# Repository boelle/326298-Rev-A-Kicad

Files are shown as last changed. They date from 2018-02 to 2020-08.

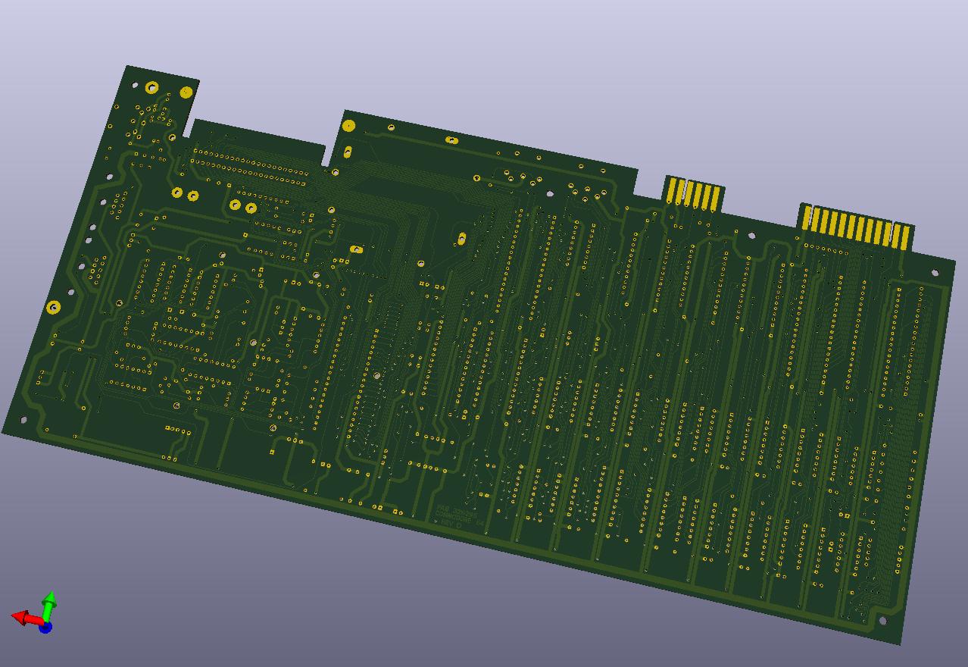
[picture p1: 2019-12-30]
GERBERS/back_3d.jpg

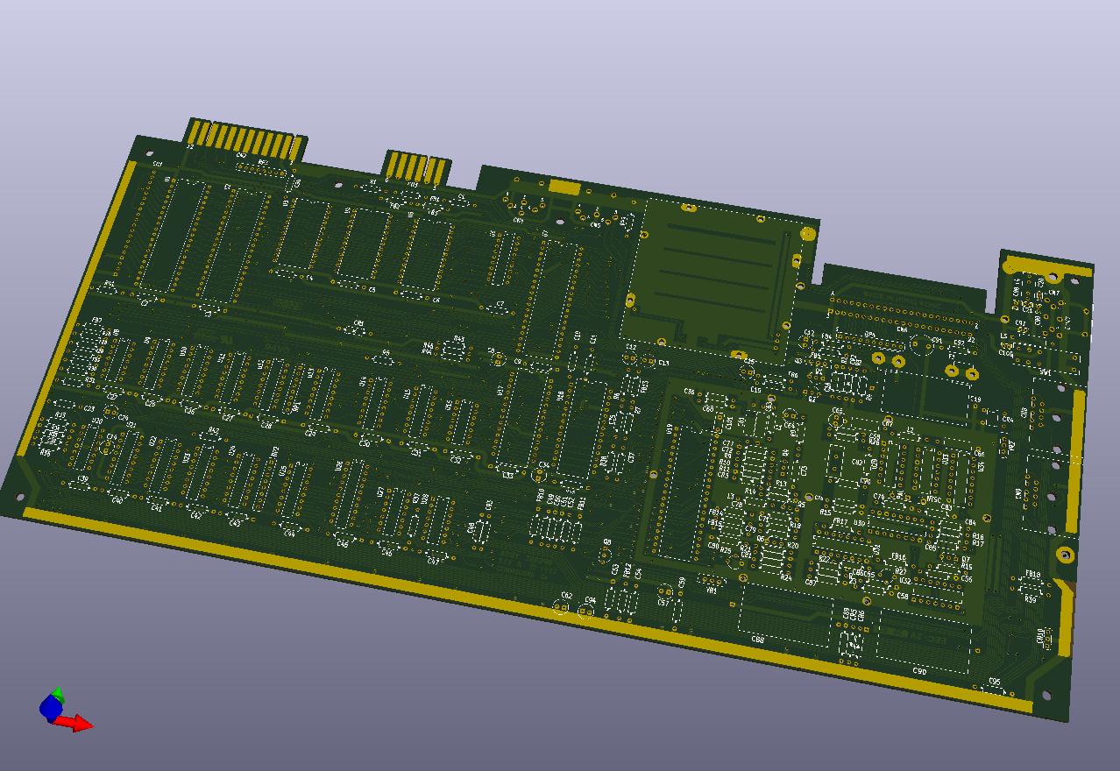
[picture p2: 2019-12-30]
GERBERS/front_3d.jpg

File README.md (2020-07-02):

Shield: [][cc-by-nc-nd]

This work is licensed under a [Attribution-NonCommercial-NoDerivatives 4.0 International License][cc-by-nc-nd].

[][cc-by-nc-nd]

[cc-by-nc-nd]: http://creativecommons.org/licenses/by-nc-nd/4.0/
[cc-by-nc-nd-image]: https://licensebuttons.net/l/by-nc-nd/4.0/88x31.png
[cc-by-nc-nd-shield]: https://img.shields.io/badge/License-CC%20BY--NC--ND%204.0-lightgrey.svg

# What is this?

It's my project/attempt at recreating the first board used in C64 production.
It's based on a schematic by Ruud Baltissen.

# How?
I got one of these boards without much components, all chips where gone (almost).
I then removed the rest and cleaned out all holes and got it scanned at a local copy shop.
Initial I used sprint layout which has a feature to trace on top of an image.
But I wanted a more "complete" soloution so I imported the copper layers in to kicad and 
managed to trace on top of that. 
But the schematic was not the same as the board and I got help from Fredric QJ Blåholtz
adjustning the schematic to the board, it's a bit backwards but I trust the board more.

# Why?
I have been asked that a lot. One reason is that I have always liked the C64 and I
wanted to get more intimate with it. One thing I have truly learned is that QA and QC 
was not that much used 37 years ago, anything that worked was ok. So boards could differ 
even thou they had the same number. So I decided to just stick with making a replica of
what I had. 

The other reason is that I have a lot of time on my hands so I wanted to make
something, that at some point will come in as usefull. These boards will at some point fail.
They where not robust made 37 years ago and either a hole will break loose from the board
or a track will crack. Having a source for a new board would then come in handy. Simply
pick a PCB house that you trust and send them the gerber files. Most have a minimum order
so you will never have a problem again.

# Status?
I have verified the board by printing out the tracks on paper and used a needle to poke
through and see if things match up. It does very close but since paper under the real board
can move it will not be precise, but it's as good as I can do it.

I have also added some "eyecandy" in the form of 3d shapes of most things on the board. 
there are some things I can't find thou and my skills are not up to doing that from scratch,
but if anyone wants to chip in I need step/stp files for these parts:

# Plan?
At summer 2020 I will order 5 boards as that is the minimum from Elecrow. I will then
during fall/winter buy and add components. Since the chips are the most expensive parts,
it might be as far as early 2021 before i can power it up

# Working on right now?
Trying to locate cad/3d models in step/stp format for the missing bits

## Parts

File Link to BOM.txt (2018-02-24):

https://docs.google.com/spreadsheets/d/1Gl0Q71u6fKLPRA9HQiSG8-xY8tPweMwXuy_UGQ1Iayo/edit?usp=sharing

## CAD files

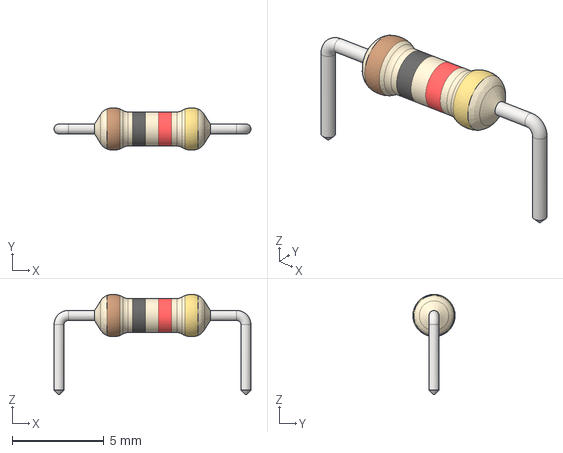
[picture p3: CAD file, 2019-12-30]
1 Kohm resistor/1,0 kOhm R Axial DIN0207 L6.3mm D2.5mm P10.16mm Horizontal.stp
10.7 x 2.30 x 5.45 mm

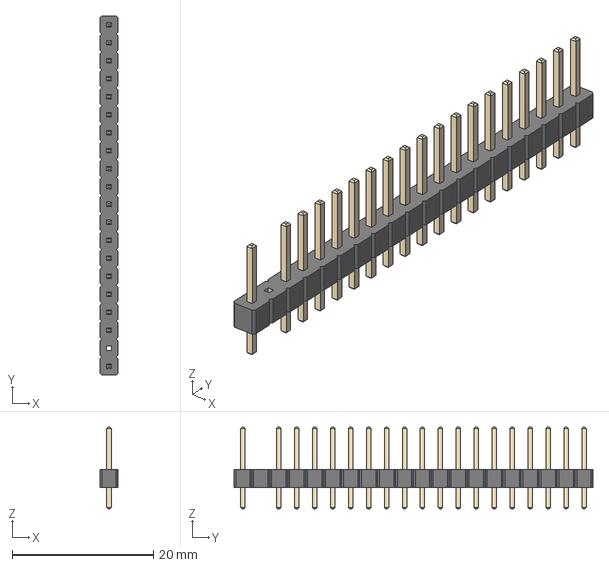
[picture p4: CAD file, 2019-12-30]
1x20 pin connector/PinHeader_1x20_P2.54mm_Vertical.step
2.54 x 50.8 x 11.5 mm

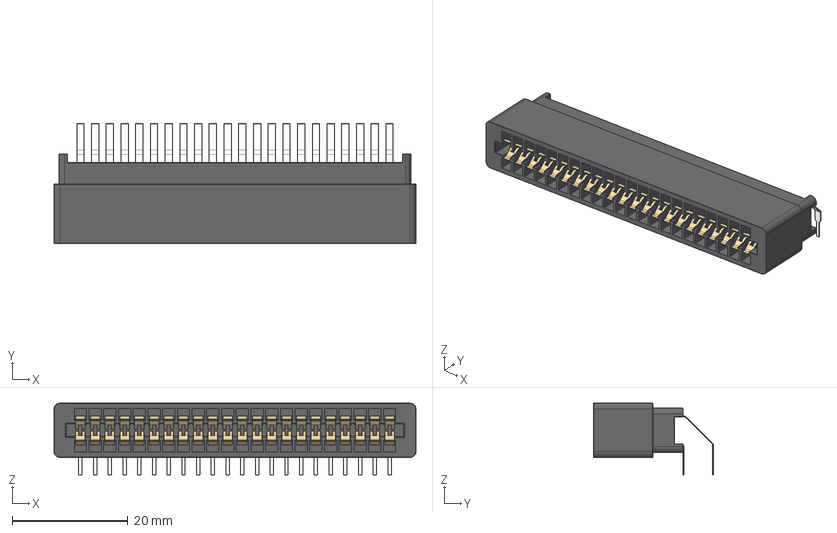
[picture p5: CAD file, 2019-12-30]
44 pin edge connector/EDGE PCB Connector P2.54mm 44pin 2 Rows Right Angle.stp
62.5 x 20.7 x 12.3 mm
EDGE Card Connector 44pos Body
EDGE Connector 2.54mm Contact Right Angle Upper x 22
EDGE Connector 2.54mm Contact Right Angle Lower x 22

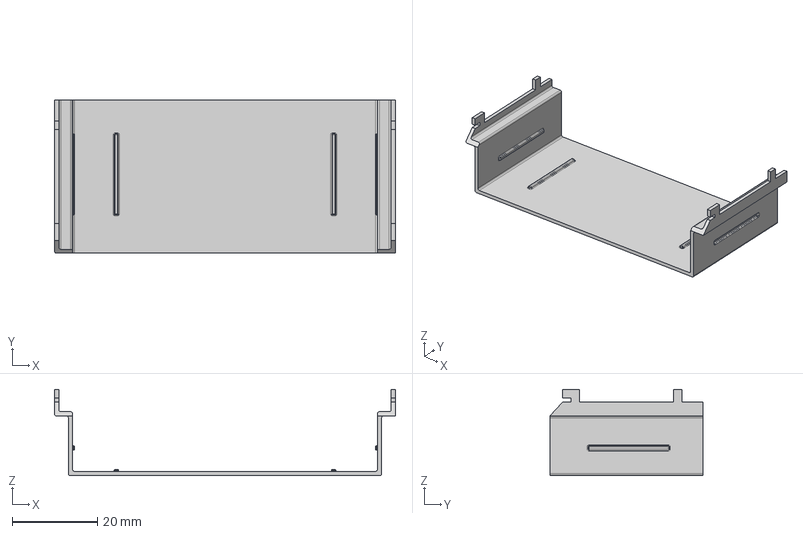
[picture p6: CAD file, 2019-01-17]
exp. port bracket/exp. port bracket.step
80.0 x 36.0 x 20.2 mm

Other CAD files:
1 Mohm resistor/1,0 MOhm R Axial DIN0207 L6.3mm D2.5mm P10.16mm Horizontal.stp
1.2 Kohm resistor/1,2 kOhm R Axial DIN0207 L6.3mm D2.5mm P10.16mm Horizontal.stp
1.5 Kohm resistor/1,5 kOhm R Axial DIN0207 L6.3mm D2.5mm P10.16mm Horizontal.stp
10 Kohm resistor/10,0 kOhm R Axial DIN0207 L6.3mm D2.5mm P10.16mm Horizontal.stp
100 Ohm resistor/100,0 Ohm R Axial DIN0207 L6.3mm D2.5mm P10.16mm Horizontal.stp
120 Ohm resistor/120,0 Ohm R Axial DIN0207 L6.3mm D2.5mm P10.16mm Horizontal.stp
3.3kohm resistor/3,3 kOhm R Axial DIN0207 L6.3mm D2.5mm P10.16mm Horizontal.stp
390 Ohm resistor/390,0 Ohm R Axial DIN0207 L6.3mm D2.5mm P10.16mm Horizontal.stp
4.7 Kohm resistor/4,7 kOhm R Axial DIN0207 L6.3mm D2.5mm P10.16mm Horizontal.stp
47 Kohm resistor/47,0 kOhm R Axial DIN0207 L6.3mm D2.5mm P10.16mm Horizontal.stp
470 Kohm resistor/470,0 kOhm R Axial DIN0207 L6.3mm D2.5mm P10.16mm Horizontal.stp
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

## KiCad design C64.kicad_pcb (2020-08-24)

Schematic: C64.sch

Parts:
C1, C2, C3, C16, C18, C22, C30, C31, C32, C35, C39, C45, C46, C47, C55, C56, C58, C68, C71, C74, C76, C77, C82, C84, C87, C89, C95, C96: 0.1 uF; 12_03_07
C4, C5, C6, C7, C9, C29, C33, C44, C51, C60, C85: 0.47 uF; 12_03_07
C8, C12, C13, C14, C15, C17, C24, C34, C57, C62, C64, C65, C94: 10 uF 25V; CAPACITOR_ELECTROLYTIC_2.5_6
C10, C11: 2200 pF Polyester; polyester12_03_07
C19: 2200 uF 16V; E37-31.5-17.5-E
C20, C21, C97, C98, C99, C100: 0.22 uF 100V; 0203
C23: 360 pF; 12_03_07
C25, C26, C27, C28, C40, C41, C42, C43, C50, C54, C59, C92: 0.22 uF; 12_03_07
C36: 20 pF 50V; 12_03_07
C37, C48, C93: 1000 pF; 12_03_07
C38, C80: 51 pF; 12_03_07
C49, C52: 470 pF 50V; 12_03_07
C53: 470 pF; 12_03_07
C61, C63, C66, C67: 0.47 uF 50V 20%; 15_4_10
C70: 10 pF 5%; 12_03_07
C72, C78: 220 pF 50V; 12_03_07
C73: 150 pF 50V; 12_03_07
C79: 510 pF; 12_03_07
C81: 20 pF; 12_03_07
C83: 33 pF; 12_03_07
C86: 39 pF 50V 5%; 12_03_07
C88, C90: 470 uF 50V; E37-31.5-17.5-E
C91: 100 uF 16V; C_E_5-9
C101: 0.1 uF; P5
CN1: KEYBOARD; 20way
CN2: USERPORT
CN3: CASSETTEPORT
CN4: DIN6
CN5: DIN5
CN6: EXPANSIONPORT
CN7: DIN7
CN8, CN9: CONTROL_PORT
CR1: 1N4371 2.7 V; D-12_3_7
CR2: 7.5 V; D-12_3_7
CR3: 1N914; D-12_3_7
CR4: BRIDGE_RECTIFIER
CR5, CR6: 1N4001; D-12_3_7
F1: 1A; SH32
FB1, FB2, FB3, FB4, FB5, FB6, FB7, FB8, FB9, FB10, FB11, FB12, FB13, FB14, FB15, FB16, FB17, FB18: FERRITE_BEAD
FRAME1: FRAME_D_L
J1, J2, J3: Conn_01x01; Socket_Strip_Straight_1x01_Pitch2.54mm
JP2E1: CN10; 3way
L1, L2: 2.2 uH; 12_03_07
L3: 3 uH; 12_03_07
L4: LINEFILTER
L5: 1.2 uH; P15
Q1: 2N4401; TO92
Q2: 2N3904; TO92
Q3: TIP29B
Q4, Q5, Q6, Q7, Q8: PN2222; TO92
R1, R24, R43, R44, R45: 3.3 K; 12_03_07
R2, R5, R15, R22: 1.5 K; 12_03_07
R3, R7: 10 K; 12_03_07
R4, R6, R13, R16, R23, R28, R29, R30, R31, R36, R38: 1 K; 12_03_07
R8, R39: 390; 12_03_07
R9, R26: 75; 12_03_07
R10, R11: 120; 12_03_07
R14: 100; 12_03_07
R17: 1.2 K; 12_03_07
R18: 230; 12_03_07
R19: 15 K; 12_03_07
R20, R37: 6.8 K; 12_03_07
R21: 4.7 K; 12_03_07
R25: 1 K Trim Pot; POT_METER
R27: 2 K Trim Pot; POT_METER
R33, R34: 47 K; 12_03_07
R35: 470 K; 12_03_07
R41: 1 M; 12_03_07
R42: 0; 12_03_07
R46: 2.1 K; 12_03_07
R49: 470; 12_03_07
RF1: RF-MODULATOR
RP1, RP2: 33; RESISTOR_PACK_4
RP3: 3.3 K; RESISTOR_PACK_4
RP4: 3.3 K; RESISTOR_PACK_9
SW1: DPDT_SWITCH
U1, U2: 6526
U3, U4: 2364
U5: 2332
U6: 2114
U7: 6510
U8: SN7406NN
U9, U10, U11, U12, U21, U22, U23, U24: 4164
U13, U25: SN74257N
U14: SN74258N
U15: SN74139N
U16, U28: 4066
U17: C64PLA
U18: 6581
U19: 6569
U20: 556DIGITAL
U26: SN74373N; 74373N
U27: SN7408N
U29: SN7474N
U30: SN74193N
U31: SN74629
U32: MC4044
U33: 74LS02; 7402
U34: 74LS175; SN74629
VR1: 7812; VR
VR2: 7805; VR
Y1: 17.73 MHz; HC49TL-H

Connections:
/+5Vc: C55.1, C56.1, C67.1, C68.1, C74.1, C82.1, C84.1, J1.1, L2.2, Q7.3 (C), R16.1, R23.1, R26.1, R27.E, U29.10 (PRE), U29.13 (CLR), U29.14 (VCC), U30.4 (CNT-DWN), U30.15 (A), U30.16 (VCC), U31.16 (VCC), U32.14 (VCC)
/+5Vcan: C60.1, C63.1, C64.+ (1), C65.+ (1), C66.1, C101.1, L1.1, L2.1, U19.40 (VCC), VR2.3 (VO)
/+5Vvid: C61.1, C71.1, C77.1, L1.2, Q4.3 (C), Q5.3 (C), R8.1, R13.1
/+9V: C18.1, C19.+ (1), C95.1, CR4.1 (+), CR6.1 (A), Q1.3 (C), Q3.2 (C), R2.1, VR2.1 (VI)
/+12V: C52.1, C53.1, C57.+ (1), C59.1, C62.+ (1), C94.+ (1), FB11.1, FB12.1, Q8.3 (C), VR1.3 (VO)
/A0: CN6.Y (A0), U1.38 (RS0), U2.38 (RS0), U3.8 (A0), U4.8 (A0), U5.8 (A0), U6.5 (A0), U7.7 (A0), U18.9 (A0), U25.13 (4B), U26.6 (3Q)
/A1: CN6.X (A1), U1.37 (RS1), U2.37 (RS1), U3.7 (A1), U4.7 (A1), U5.7 (A1), U6.6 (A1), U7.8 (A1), U18.10 (A1), U25.10 (3B), U26.12 (5Q)
/A2: CN6.W (A2), U1.36 (RS2), U2.36 (RS2), U3.6 (A2), U4.6 (A2), U5.6 (A2), U6.7 (A2), U7.9 (A2), U18.11 (A2), U25.6 (2B), U26.9 (4Q)
/A3: CN6.V (A3), U1.35 (RS3), U2.35 (RS3), U3.5 (A3), U4.5 (A3), U5.5 (A3), U6.4 (A3), U7.10 (A3), U18.12 (A3), U25.3 (1B), U26.15 (6Q)
/A4: CN6.U (A4), U3.4 (A4), U4.4 (A4), U5.4 (A4), U6.3 (A4), U7.11 (A4), U13.13 (4B), U18.13 (A4), U26.16 (7Q)
/A5: CN6.T (A5), U3.3 (A5), U4.3 (A5), U5.3 (A5), U6.2 (A5), U7.12 (A5), U13.6 (2B), U26.19 (8Q)
/A6: CN6.S (A6), U3.2 (A6), U4.2 (A6), U5.2 (A6), U6.1 (A6), U7.13 (A6), U13.3 (1B), U26.5 (2Q)
/A7: CN6.R (A7), U3.1 (A7), U4.1 (A7), U5.1 (A7), U6.17 (A7), U7.14 (A7), U26.2 (1Q)
/A8: CN6.P (A8), U3.23 (A8), U4.23 (A8), U5.23 (A8), U6.16 (A8), U7.15 (A8), U15.14 (A), U19.32 (A8), U25.14 (4A)
/A9: CN6.N (A9), U3.22 (A9), U4.22 (A9), U5.22 (A9), U6.15 (A9), U7.16 (A9), U15.13 (B), U19.33 (A9), U25.11 (3A)
/A10: CN6.M (A10), U3.19 (A10), U4.19 (A10), U5.19 (A10), U7.17 (A10), U15.2 (A), U19.34 (A10), U25.5 (2A)
/A11: CN6.L (A11), U3.18 (A11), U4.18 (A11), U5.18 (A11), U7.18 (A11), U15.3 (B), U19.23 (A11), U25.2 (1A)
/A12: CN6.K (A12), RP4.9 (X), U3.21 (A12), U4.21 (A12), U7.19 (A12), U13.14 (4A), U17.27 (A12)
/A13: CN6.J (A13), RP4.7 (X), U7.20 (A13), U13.5 (2A), U17.2 (A13)
/A14: CN6.H (A14), RP4.5 (X), U7.22 (A14), U13.2 (1A), U17.3 (A14)
/A15: CN6.F (A15), RP4.4 (X), U7.23 (A15), U13.11 (3A), U17.4 (A15)
/D0: CN6.21 (D0), U1.33 (D0), U2.33 (D0), U3.9 (O0), U4.9 (O0), U5.9 (O0), U7.37 (D0), U16.11 (Y3), U18.15 (D0), U19.7 (D0), U21.2 (DI), U21.14 (DO)
/D1: CN6.20 (D1), U1.32 (D1), U2.32 (D1), U3.10 (O1), U4.10 (O1), U5.10 (O1), U7.36 (D1), U9.2 (DI), U9.14 (DO), U16.8 (Y2), U18.16 (D1), U19.6 (D1)
/D2: CN6.19 (D2), U1.31 (D2), U2.31 (D2), U3.11 (O2), U4.11 (O2), U5.11 (O2), U7.35 (D2), U16.4 (Y1), U18.17 (D2), U19.5 (D2), U22.2 (DI), U22.14 (DO)
/D3: CN6.18 (D3), U1.30 (D3), U2.30 (D3), U3.13 (O3), U4.13 (O3), U5.13 (O3), U7.34 (D3), U10.2 (DI), U10.14 (DO), U16.1 (Y0), U18.18 (D3), U19.4 (D3)
/D4: CN6.17 (D4), U1.29 (D4), U2.29 (D4), U3.14 (O4), U4.14 (O4), U5.14 (O4), U7.33 (D4), U18.19 (D4), U19.3 (D4), U23.2 (DI), U23.14 (DO)
/D5: CN6.16 (D5), U1.28 (D5), U2.28 (D5), U3.15 (O5), U4.15 (O5), U5.15 (O5), U7.32 (D5), U11.2 (DI), U11.14 (DO), U18.20 (D5), U19.2 (D5)
/D6: CN6.15 (D6), U1.27 (D6), U2.27 (D6), U3.16 (O6), U4.16 (O6), U5.16 (O6), U7.31 (D6), U18.21 (D6), U19.1 (D6), U24.2 (DI), U24.14 (DO)
/D7: CN6.14 (D7), U1.26 (D7), U2.26 (D7), U3.17 (O7), U4.17 (O7), U5.17 (O7), U7.30 (D7), U12.2 (DI), U12.14 (DO), U18.22 (D7), U19.39 (D7)
/IRQ: CN6.4 (IRQ), RP4.2, U1.21 (~IRQ~), U7.3 (~IRQ~), U19.8 (~IRQ~)
/MA0: RP2.4 (2), U9.5 (A0), U10.5 (A0), U11.5 (A0), U12.5 (A0), U21.5 (A0), U22.5 (A0), U23.5 (A0), U24.5 (A0)
/MA1: RP2.8 (2), U9.7 (A1), U10.7 (A1), U11.7 (A1), U12.7 (A1), U21.7 (A1), U22.7 (A1), U23.7 (A1), U24.7 (A1)
/MA2: RP2.6 (2), U9.6 (A2), U10.6 (A2), U11.6 (A2), U12.6 (A2), U21.6 (A2), U22.6 (A2), U23.6 (A2), U24.6 (A2)
/MA3: RP2.2, U9.12 (A3), U10.12 (A3), U11.12 (A3), U12.12 (A3), U21.12 (A3), U22.12 (A3), U23.12 (A3), U24.12 (A3)
/MA4: RP1.4 (2), U9.11 (A4), U10.11 (A4), U11.11 (A4), U12.11 (A4), U21.11 (A4), U22.11 (A4), U23.11 (A4), U24.11 (A4)
/MA5: RP1.6 (2), U9.10 (A5), U10.10 (A5), U11.10 (A5), U12.10 (A5), U21.10 (A5), U22.10 (A5), U23.10 (A5), U24.10 (A5)
/MA6: RP1.2, U9.13 (A6), U10.13 (A6), U11.13 (A6), U12.13 (A6), U21.13 (A6), U22.13 (A6), U23.13 (A6), U24.13 (A6)
/MA7: RP1.8 (2), U9.9 (A7), U10.9 (A7), U11.9 (A7), U12.9 (A7), U21.9 (A7), U22.9 (A7), U23.9 (A7), U24.9 (A7)
/N$1: C12.+ (1), C35.1, U18.26 (EXT-IN)
/N$2: FB13.1, R6.1, U18.27 (AUDIO-OUT)
/N$3: FB13.2, R7.1
/N$4: C37.1, Q8.2 (B), R7.2
/N$5: C13.+ (1), Q8.1 (E), R38.1
/N$6: C10.2, U18.2 (CAP1B)
/N$7: C11.2, U18.4 (CAP2B)
/N$8: C10.1, U18.1 (CAP1A)
/N$9: C11.1, U18.3 (CAP2A)
/N$10: C13.- (2), CN5.3, RF1.AUDI (AUDIO)
/N$11: C12.- (2), CN5.5
/N$12: C34.+ (1), C50.1, FB10.1, R46.1, U18.25 (VCC)
/N$13: C16.1, FB6.2, RF1.+ (+V)
/N$14: C51.1, FB11.2, U18.28 (V12)
/N$15: C80.1, FB14.2, R25.A
/N$16: FB14.1, U19.14 (COLOR)
/N$17: C97.1, CN7.4, CN7.5, L5.1
/N$18: C100.1, L5.2, SW1.2
/N$19: C20.2, CN7.6, L4.4
/N$20: C20.1, CN7.7, L4.2
/N$21: C21.1, C98.1, F1.1A, F1.1B, L4.3
/N$22: C21.2, C99.1, L4.1, SW1.5
/N$23: CN2.11 (9VAC1), CR4.4 (AC2), F1.2A, F1.2B, R5.1
/N$24: C90.- (2), CN2.10 (9VAC2), CR4.3 (AC1), SW1.6 (O)
/N$26: C90.+ (1), CR5.1 (A), CR6.2 (C)
/N$27: C88.+ (1), C89.1, CR5.2 (C), VR1.1 (VI)
/N$28: R24.1, R25.S
/N$29: C81.2, R24.2
/N$30: C81.1, Q6.2 (B), R20.1, R21.1
/N$31: Q5.2 (B), Q6.3 (C), R13.2, R20.2
/N$32: C79.2, Q5.1 (E), R14.1
/N$33: L3.1, R10.2, R11.2, R18.1
/N$35: C54.1, FB12.2, U19.13 (V12)
/N$36: C73.1, CR3.1 (A), Q4.2 (B), R8.2
/N$37: CR3.2 (C), FB15.2
/N$38: Q4.1 (E), R9.1, R10.1
/N$39: C72.1, CN5.1, R9.2
/N$41: C78.1, CN5.4, L3.2, R49.1, RF1.VIDE (VIDEO)
/N$42: U14.10 (3B), U14.11 (3A), U19.31 (A7)
/N$44: U14.13 (4B), U14.14 (4A), U19.30 (A6)
/N$45: U14.3 (1B), U14.12 (4Y)
/N$46: U14.6 (2B), U14.9 (3Y)
/N$47: U6.14 (D0), U16.10 (Z3), U19.38 (D8)
/N$48: U6.13 (D1), U16.9 (Z2), U19.37 (D9)
/N$49: U6.12 (D2), U16.3 (Z1), U19.36 (D10)
/N$50: U6.11 (D3), U16.2 (Z0), U19.35 (D11)
/N$51: R42.2, U17.18 (CASRAM)
/N$52: U8.11 (I), U14.15 (G), U16.5 (E1), U16.6 (E2), U16.12 (E3), U16.13 (E0), U19.16 (AEC), U26.1 (OC), U27.4 (I0), U27.10 (I1)
/N$53: U8.13 (I), U13.1 (~A~/B), U14.1 (~A~/B), U17.9 (CAS), U19.19 (~CAS~), U25.1 (~A~/B)
/N$54: R42.1, U9.15 (~CAS), U10.15 (~CAS), U11.15 (~CAS), U12.15 (~CAS), U21.15 (~CAS), U22.15 (~CAS), U23.15 (~CAS), U24.15 (~CAS)
/N$55: U9.4 (~RAS), U10.4 (~RAS), U11.4 (~RAS), U12.4 (~RAS), U19.18 (~RAS~), U21.4 (~RAS), U22.4 (~RAS), U23.4 (~RAS), U24.4 (~RAS), U26.11 (ENC)
/N$56: U6.8 (~CS), U27.8 (O)
/N$59: C24.- (2), R34.2, U20.8 (TR), U20.12 (THR)
/N$60: U8.5 (I), U20.5 (Q)
/N$61: C23.1, R33.2, U20.1 (DIS), U20.2 (THR)
/N$62: C38.2, R35.1, U20.6 (TR)
/N$63: C38.1, CN1.3, R41.2
/N$64: R26.2, U31.15 (I1)
/N$65: C58.1, R27.S, U31.1 (VCO)
/N$66: FB16.1, U31.10 (Y1)
/N$67: C70.2, U31.13 (X2)
/N$68: U31.12 (X1), Y1.2
/N$69: C70.1, Y1.1
/N$70: FB16.2, U19.21 (COLCLK), U30.5 (CNT-UP)
/N$71: C83.1, U30.11 (LOAD), U30.12 (CRY)
/N$72: J3.1, U29.4 (PRE), U30.1 (C), U30.10 (B)
/N$73: U29.5 (Q), U30.9 (D)
/N$74: R16.2, R17.2, U31.2 (FREQ), U32.8 (BO)
/N$75: U29.11 (CLK), U30.6 (QC)
/N$76: U29.8 (~Q), U29.12 (D)
/N$77: U32.2 (PDO2), U32.11 (CPI2)
/N$78: U32.4 (CPI1), U32.13 (PDO1)
/N$79: C87.1, R22.1, R23.2, U31.3 (I3)
/N$80: C86.1, U31.4 (C1)
/N$81: C86.2, U31.5 (C2)
/N$82: FB17.1, U31.7 (Y2)
/N$83: U29.9 (Q), U32.1 (PDI1)
/N$84: CN3.5 (WRITE1), CN3.E (WRITE2), FB1.1
/N$85: R19.2, U32.5 (CPI3), U32.10 (CPO)
/N$86: C85.1, R17.1
/N$87: C36.1, CN6.6 (DOTCLK), FB17.2, U19.22 (DOTCLK)
/N$88: C85.2, Q7.2 (B), R19.1
/N$89: R31.2, U8.10 (O), U13.15 (G), U17.25 (AEC), U25.15 (G)
/N$90: Q7.1 (E), U32.9 (BI)
/N$91: CN1.19, CN8.2, U1.3 (PA1)
/N$92: CN1.18, CN8.3, U1.4 (PA2)
/N$93: CN1.17, CN8.4, U1.5 (PA3)
/N$94: CN1.16, CN8.6, U1.6 (PA4)
/N$95: CN1.15, U1.7 (PA5)
/N$96: CN1.14, U1.8 (PA6), U28.6 (E2), U28.12 (E3)
/N$97: CN1.20, U1.9 (PA7), U28.5 (E1), U28.13 (E0)
/N$98: CN1.13, CN8.1, U1.2 (PA0)
/N$99: CN1.12, CN9.1, U1.10 (PB0)
/N$100: CN1.11, CN9.2, U1.11 (PB1)
/N$101: CN1.10, CN9.3, U1.12 (PB2)
/N$102: CN1.9, U1.17 (PB7)
/N$103: CN1.8, CN9.6, U1.14 (PB4), U19.9 (LP)
/N$104: CN1.7, U1.15 (PB5)
/N$105: CN1.5, CN9.4, U1.13 (PB3)
/N$106: CN1.6, U1.16 (PB6)
/N$107: CN8.9, U28.1 (Y0)
/N$108: CN8.5, U28.4 (Y1)
/N$109: CN8.7, CN9.7, FB18.1
/N$110: CN9.9, U28.8 (Y2)
/N$111: CN9.5, U28.11 (Y3)
/N$113: C93.2, U18.23 (POTY), U28.3 (Z1), U28.10 (Z3)
/N$114: CN4.3, FB7.1
/N$115: CN4.4, FB9.1
/N$116: CN4.5, FB8.1
/N$117: FB8.2, R29.2, U2.9 (PA7), U8.4 (O)
/N$118: FB9.2, R30.2, U2.8 (PA6), U8.8 (O)
/N$119: CN2.9 (ATN), FB7.2, R28.2, U8.2 (O)
/N$120: CN2.8 (PC2), U2.18 (~PC~)
/N$121: CN2.L (PB7), U2.17 (PB7)
/N$122: CN2.K (PB6), U2.16 (PB6)
/N$123: CN2.J (PB5), U2.15 (PB5)
/N$124: CN2.H (PB4), U2.14 (PB4)
/N$125: CN2.F (PB3), U2.13 (PB3)
/N$126: CN2.E (PB2), U2.12 (PB2)
/N$127: CN2.D (PB1), U2.11 (PB1)
/N$128: CN2.C (PB0), U2.10 (PB0)
/N$129: CN2.B (FLAG2), RP3.2, U2.24 (~FLAG~)
/N$130: U2.7 (PA5), U8.3 (I)
/N$131: U2.6 (PA4), U8.9 (I)
/N$132: U2.5 (PA3), U8.1 (I)
/N$133: CN3.3 (MOTOR1), CN3.C (MOTOR2), FB2.1
/N$134: CN2.4 (CNT1), RP3.5 (X), U1.40 (CNT)
/N$135: U2.2 (PA0), U14.2 (1A), U17.5 (VIA14)
/N$136: U2.3 (PA1), U14.5 (2A)
/N$137: CN2.M (PA2), U2.4 (PA2)
/N$138: CN2.7 (SP2), RP3.8 (X), U2.39 (SP)
/N$139: CN2.6 (CNT2), RP3.7 (X), U2.40 (CNT)
/N$140: CN2.5 (SP1), RP3.6 (X), U1.39 (SP)
/N$141: FB5.1, U7.39 (CLKOUT)
/N$143: C76.1, R15.1, U31.14 (RNG)
/N$145: U3.20 (CS), U17.17 (BASIC)
/N$146: CR1.2 (C), R5.2, R37.2, U27.12 (I0)
/N$147: R37.1, U1.19 (TOD), U2.19 (TOD), U27.11 (O)
/N$148: JP2E1.1, JP2E1.3, R39.2; also elsewhere on the board
/N$152: U4.20 (CS), U17.16 (KERNAL)
/N$153: CN6.C (RESET), FB4.1
/N$155: CN6.12 (BA), U17.26 (BA), U19.12 (BA), U27.1 (I0), U33.2 (I1), U33.12 (I1)
/N$157: CN6.11 (ROML), U17.11 (ROML)
/N$158: CN6.B (ROMH), U17.10 (ROMH)
/N$159: CN6.9 (EXROM), RP4.8 (X), U17.23 (EXROM)
/N$160: CN6.8 (GAME), RP4.6 (X), U17.22 (GAME)
/N$162: FB15.1, U19.15 (SYNC)
/N$163: U15.4 (Y0), U19.10 (~CS~)
/N$164: R45.2, U7.29 (P0), U17.8 (LORAM)
/N$165: R44.2, U7.28 (P1), U17.7 (HIRAM)
/N$166: R43.2, U7.27 (P2), U17.6 (CHAREN)
/N$167: U7.2 (RDY), U27.3 (O)
/N$168: U7.5 (AEC), U27.6 (O)
/N$169: CN6.13 (DMA), RP4.10 (X), U27.2 (I1), U27.5 (I1)
/N$170: U5.20 (CS1), U17.15 (CHAROM)
/N$171: CN3.4 (READ1), CN3.D (READ2), CN4.1, RP3.4 (X), U1.24 (~FLAG~)
/N$172: CN3.6 (SENSE1), CN3.F (SENSE2), R1.2, U7.25 (P4)
/N$173: C1.1, CN3.2 (VCC1), CN3.B (VCC2), FB3.1
/N$176: FB1.2, U7.26 (P3)
/N$177: Q2.2 (B), R3.1, R4.2
/N$178: Q1.1 (E), Q3.1 (B)
/N$179: C18.2, CR2.2 (C), Q1.2 (B), Q2.3 (C), R2.2
/N$180: FB2.2, Q3.3 (E)
/N$181: R4.1, U7.24 (P5)
/N$182: U1.23 (~CS~), U15.12 (Y0)
/N$183: U2.23 (~CS~), U15.11 (Y1)
/N$184: U6.10 (~WE), U17.13 (GR/W)
/N$185: U15.1 (G), U17.12 (I/O)
/N$186: U15.7 (Y3), U15.15 (G)
/N$187: CN6.7 (IO1), U15.10 (Y2)
/N$188: CN6.10 (IO2), U15.9 (Y3)
/N$189: U15.5 (Y1), U18.8 (CS)
/N$190: U15.6 (Y2), U27.9 (I0)
/NA0: RP2.3 (1), U19.24 (A0/A8), U25.12 (4Y), U26.7 (3D)
/NA1: RP2.7 (1), U19.25 (A1/A9), U25.9 (3Y), U26.13 (5D)
/NA2: RP2.5 (1), U19.26 (A2/A10), U25.7 (2Y), U26.8 (4D)
/NA3: RP2.1, U19.27 (A3/A11), U25.4 (1Y), U26.14 (6D)
/NA4: RP1.3 (1), U13.12 (4Y), U17.20 (VA12), U19.28 (A4/A12), U26.17 (7D)
/NA5: RP1.5 (1), U13.7 (2Y), U17.21 (VA13), U19.29 (A5/A13), U26.18 (8D)
/NA6: RP1.1, U13.4 (1Y), U14.4 (1Y), U26.4 (2D)
/NA7: RP1.7 (1), U13.9 (3Y), U14.7 (2Y), U26.3 (1D)
/NMI: CN6.D (NMI), RP3.3 (X), U2.21 (~IRQ~), U7.4 (~NMI~), U8.6 (O)
/PHI0: U7.1 (CLKIN), U19.17 (PHI0), U32.3 (PDI2), U33.5 (I1)
/PHI2: CN6.E (PHI2), FB5.2, U1.25 (CLKOUT), U2.25 (CLKOUT), U18.6 (CLKOUT)
/RES: CN2.3 (RESET), CN4.6, FB4.2, R36.2, U1.34 (~RES~), U2.34 (~RES~), U7.40 (~RES~), U18.5 (RESET), U20.9 (Q), U20.13 (DIS)
/RW: CN6.5 (R/W), R46.2, RP4.3 (X), U1.22 (R/W), U2.22 (R/W), U7.38 (R/W), U9.3 (~WE), U10.3 (~WE), U11.3 (~WE), U12.3 (~WE), U17.24 (R/W), U18.7 (R/W), U19.11 (~R/W~), U21.3 (~WE), U22.3 (~WE), U23.3 (~WE), U24.3 (~WE)
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

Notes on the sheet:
Based on schematic done by Ruud Baltissen. Values and footprints corrected by Bo Herrmannsen Help with correcting schematic to match board by Fredric QJ Blåholtz
20-02-2018
Commodore C64 Rev A Replica Schematic
? Ends blind on board

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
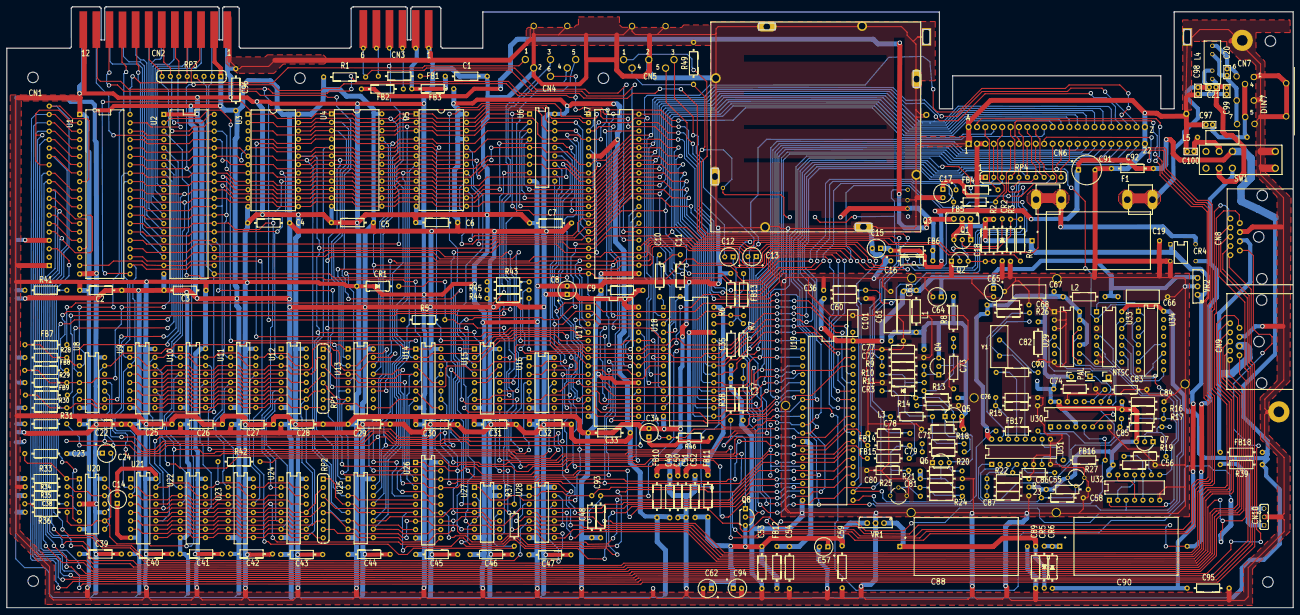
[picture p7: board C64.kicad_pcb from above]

Board: 2 copper layers, 389.2 x 181.8 mm, 237 parts (0 on the bottom side), 234 nets.

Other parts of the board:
CN10: JP2E; 3way

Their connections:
/N$148: CN10.1, CN10.3; also elsewhere on the board

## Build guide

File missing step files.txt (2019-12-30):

fb1
fb2
fb3
fb4
fb5
fb6
fb7
fb8
fb9
fb10
fb11
fb12
fb13
fb14
fb15
fb16
fb17
fb18
c1
c10
c11
c16
c18
c20
c21
c23
c35
c36
c54
c56
c58
c59
c71
c72
c74
c77
c76
c78
c79
c81
c84
c87
c89
c92
c96
c97
c98
c99
c100
u1
u2
u3
u4
u5
u6
u7
u8
u9
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
cr4
f1

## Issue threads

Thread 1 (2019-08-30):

I'm doing the same for KU motherboard

bwack, 2019-08-30:
Hi Bo. I was wondering about the state of this project? I also would like to inform that I'm walking in your footsteps to replicate the layout and make a schematics for the KU- motherboard. I'm already done the layout and imported it in KiCad for checking against the schematic that I am making. I'm drawing the schematics (and symbols and everything) very close to 250407, and using the netlist from the schematics to verify with DRC in the KiCadlayout. Did you also use the built in gerber import in KiCad ?
Maybe we can share some tips and tricks about the project of ours. Ps. check my github repository for my file. Currently I haven't shared my layout drawings yet in fear that someone will order boards before they are verified.

bwack, 2020-01-19:
I'm closing this. No reply and finished with my project.

Closed 2020-01-19.

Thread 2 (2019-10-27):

Offer help with 3D models

PCB-Tech-eu, 2019-10-27:

bwack, 2019-10-30:
I'd like to try this in my KU-14194HB C64 motherboard project. Do I need to convert the STEP files or does KiCad load them if I add them as a 3D package ?

PCB-Tech-eu, 2019-10-30:
KiCad can use STEP files directly without conversion. Simply select and position it in the Footprint Editor and you're done.

PCB-Tech-eu, 2019-11-08:
Since apparently the project doesn't need any help with the 3D models, I withdraw my free help offer!

bwack, 2019-11-08:
If you like to help me instead, I have a very similar repo that i'm working on
https://github.com/bwack/KU-14194HB-RevB-KiCad

Closed 2019-11-08.

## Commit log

2018-02-24 initial push after split up
    [C64.sch]
2018-02-25 added ground and vcc fill area's
    also adjusted a bit on schematic to make it match board
    [C64.sch]
2018-02-26 cleaned up the outer edge
    [C64.sch]
2018-02-26 more adjustment to schematic
    ~56 unconnected left. most inside the vic area
    [C64.sch]
2018-02-26 a few more adjustmenst
    ~55 unconnected left
    [C64.sch]
2018-02-26 last updates etc
    Time to take a break :-D
    [C64.sch]
2018-02-27 corrections on transistors for casseste control
    [C64.sch]
2018-02-27 forgot one track to userport
2018-02-27 fixed track at RP4
    [C64.sch]
2018-02-27 C34 cahnged to 5v can
    [C64.sch]
2018-02-27 4 connections left
    There should be a via under R46 but the 2 traks that cross each other does not have the same name
    Have checked the RES line and it all seems to connect, there must be a microscopic disconnect somewhere on the RES line
    Next step is to import all holes on one of the user layers and check that all via's are there
    [C64.sch]
2018-02-28 2 connections left
    C34 and Via under R46 is the mystery
    will need to check that all via's are in place, one missing and it can fail
    [C64.sch]
2018-02-28 added all via's from sprint layout proram on F.adhes layer
    since this will be hand assembly i'm not going to need adhesion/glue
    this will be used to check that all via's are there and it will also be used for fine adjusting placements etc
    [drill.kicad_pcb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]
2018-02-28 corrected a few more things
    Thanks to Fredric QJ Blåholtz for the help so far
    [C64.sch]
2018-02-28 added u33 and u34 on schematic
    these needs to be wired by the tracks on the board. no schematic found with them wired in
    [C64.sch]
2018-02-28 added schematic symbols for U33 and U34
    u33 needs some edit work before connections in schematic can be made
    [_saved_C64.sch]
2018-03-01 added 2 missing ic's
    these are for NTSC versions
    [C64.sch, _saved_C64.sch]
2018-03-01 added 3d shapes to ntsc chips
    [C64.sch]
2018-03-01 all tracks connected. Hurra :-D
    [C64.sch]
2018-03-01 minor corrections to casette port footprint
2018-03-01 minor corrections
    [C64.sch]
2018-03-01 more adjustments
    [C64.sch]
2018-03-01 minor adjustments to userport
    pad 1+2 done and pads 10+11 (and their counterparts on the other side of board)
2018-03-02 first adjustments on silk screen
    [C64.sch, silk.kicad_pcb]
2018-03-02 recreated edge cut
2018-03-02 outline done
    missing is milling on RF modulator and adjusting control ports and power input
    [C64.kicad_pcb]
2018-03-03 more footprints and schematic corrections
    a lot of the schematic symbols was still from the eagle import and pcb footprints had not been saved as individual footprints
    [C64.kicad_pcb, C64.sch]
2018-03-03 negative copper layers back
    will use them to adjust thickness etc
    [C64.sch, top_cobber.kicad_pcb]
2018-03-03 more supply symbols
    All symbols on schematic should now be saved as individual lib's
    [C64.sch]
2018-03-03 most supply tracks
    supply tracks roughly in place. a few is missing and they all need to be fine adjusted later
    [C64.sch]
2018-03-05 removed solder mask on front side
2018-03-06 more "polising"
    added blind ending track at FB12
2018-03-06 a few corrections on references
    Commodore placed the references for C98 and C99 wrong, have made them switch place.
    C53 and C54 the same thing.
2018-03-07 big cleanup
    [drill.kicad_pcb, silk.kicad_pcb, top_cobber.kicad_pcb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]
2018-03-07 removed old drill layer info
    this was used to place components more precise and is no longer needed
2018-03-08 silk screen 1#2
    left half of board done
2018-03-08 c54 & 53 corrected
    [C64.sch]
2018-03-10 added fuse to 3d view
2018-03-13 added silkscreen on c101 and Y1
    also checked userport and casette port. they seem to be spaced correctly from top left corner and the spacing between them also seems ok. expansion port is also the correct distance from top right corner
2018-06-18 added resistors with color rings
2018-08-04 update to 3d resistor
2019-01-17 added more 3d shapes
    also added vic area frame and exp. port bracket
    [exp. port bracket.step, vic frame.step]
2019-01-20 added logo's
    need to move them from eco1 layer to copper
    [res_0.step, res_100.step, res_1000.step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]
2019-01-21 added logo to back side
    [C64.kicad_pcb]
2019-01-22 gerbers generated
    [C64-B.Cu.gbr, C64-B.Mask.gbr, C64-B.SilkS.gbr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]
2019-02-08 hiden eco layers
    [C64.kicad_pcb]
2019-12-30 more 3d
    and board edge
    [1,0 MOhm R Axial DIN0207 L6.3mm D2.5mm P10.16mm Horizontal.stp, 1,0 kOhm R Axial DIN0207 L6.3mm D2.5mm P10.16mm Horizontal.stp, 1,2 kOhm R Axial DIN0207 L6.3mm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]
2020-01-26 Winter cleanup
    [C64_old.kicad_pcb, drill.kicad_pcb, silk.kicad_pcb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]
2020-06-16 bigger holes
    [C64.kicad_pcb, C64.sch]
2020-06-20 updated gerbers
    [C64.kicad_pcb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]
2020-08-24 expansion port pads improved
    [C64.kicad_pcb]

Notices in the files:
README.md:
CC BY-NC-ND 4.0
